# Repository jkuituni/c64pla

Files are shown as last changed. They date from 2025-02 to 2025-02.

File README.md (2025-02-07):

# c64pla
Implementation of the SuperPLA in the c64 'c' version in VHDL done together with Frank Buss. Note, that this version does work only as the normal SuperPLA (chip number 251715), not the one with integrated color SRAM (chip number 252535).

This is a fork from the Frank Buss' repository as that is where the original work was done. For additional information check out the webpage about this project :

https://frank-buss.de/c64/pla/index.html

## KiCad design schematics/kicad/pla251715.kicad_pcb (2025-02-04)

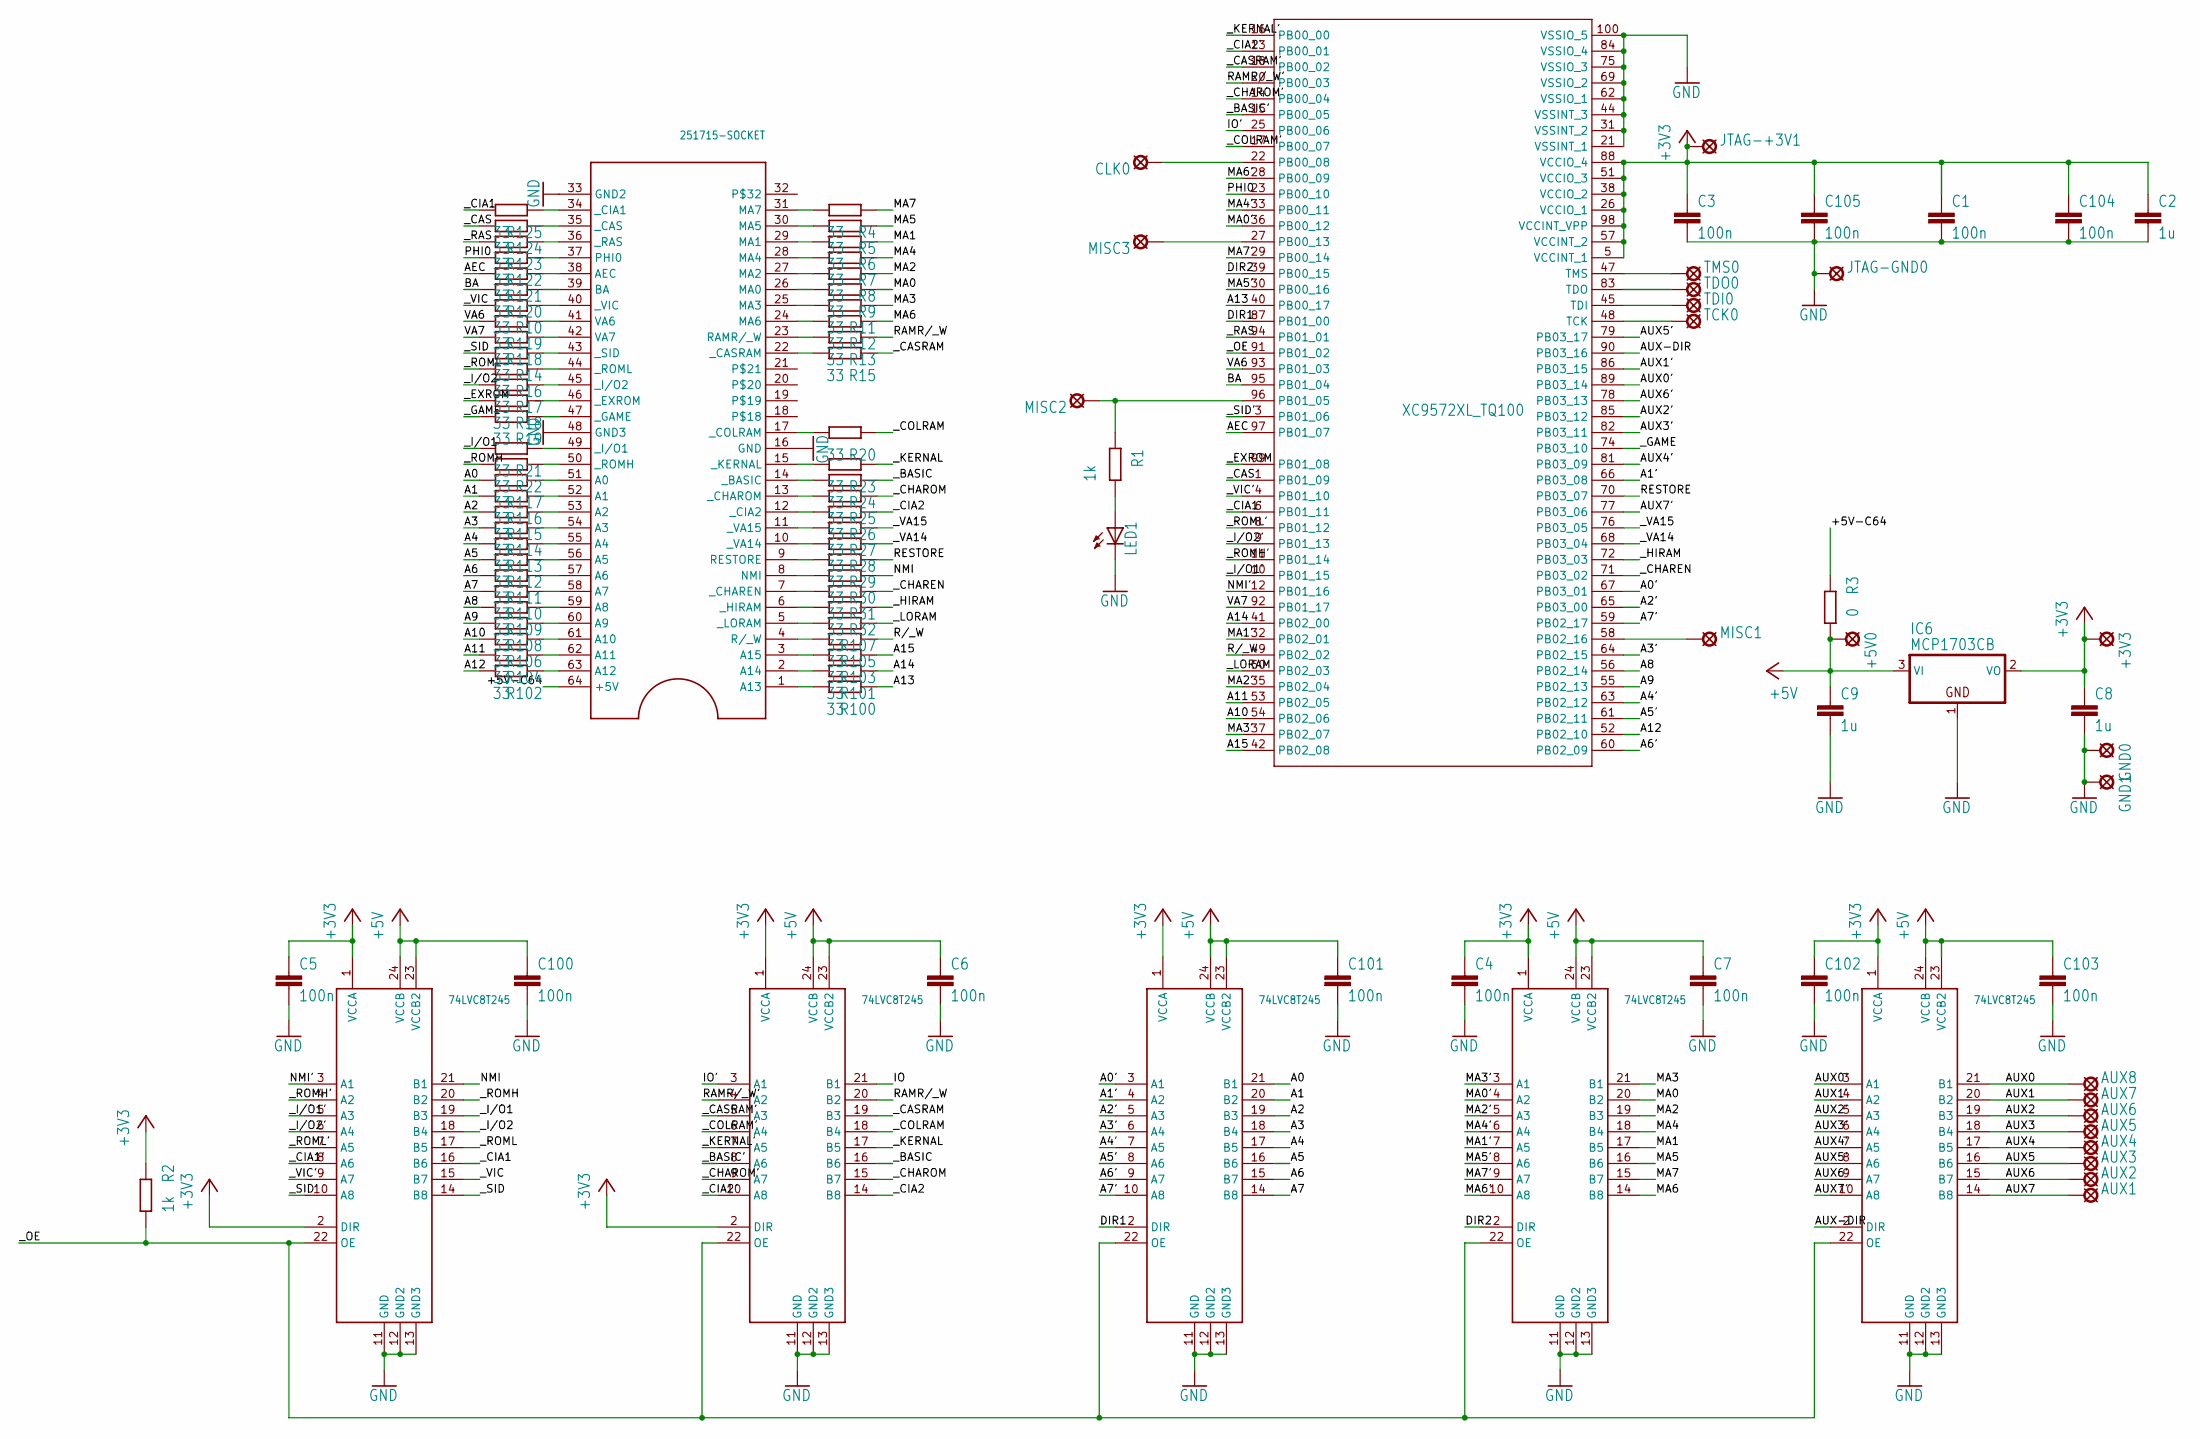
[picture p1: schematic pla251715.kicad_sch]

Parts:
+3V3, +5V0: LSP10
AUX1, AUX2, AUX3, AUX4, AUX5, AUX6, AUX7, AUX8: LSP10
C1, C3, C4, C5, C6, C7, C100, C101, C102, C103, C104, C105: 100n; C0603
C2, C8, C9: 1u; C1210
CLK0: LSP10
GND0, GND1: LSP10
IC1, IC3, IC4, IC5, IC100: 74LVC8T245; TSSOP24
IC2: XC9572XL_TQ100; TQ100
IC6: MCP1703CB; SOT23
JTAG-+3V1: LSP10
JTAG-GND0: LSP10
LED1: LED5MM
MISC1, MISC2, MISC3: LSP10
PLA-SOCKET0: 251715-SOCKET; 64-SPDIP
R1, R2: 1k; R0805
R3: 0; R0805
R4, R5, R6, R7, R8, R9, R10, R11, R12, R13, R14, R15, R16, R17, R18, R19, R20, R21, R22, R23, R24, R25, R26, R27, R28, R29, R30, R31, R32, R100, R101, R102, R103, R104, R105, R106, R107, R108, R109, R110, R111, R112, R113, R114, R115, R116, R117, R118, R119, R120, R121, R122, R123, R124, R125: 33; R0402
TCK0: LSP10
TDI0: LSP10
TDO0: LSP10
TMS0: LSP10

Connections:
+3V3: +3V3.MP, C1.1, C2.1, C3.1, C4.1, C5.1, C8.1, C102.1, C104.1, C105.1, IC1.1 (VCCA), IC2.5 (VCCINT_1), IC2.26 (VCCIO_1), IC2.38 (VCCIO_2), IC2.51 (VCCIO_3), IC2.57 (VCCINT_2), IC2.88 (VCCIO_4), IC2.98 (VCCINT_VPP), IC3.1 (VCCA), IC3.2 (DIR), IC4.1 (VCCA), IC4.2 (DIR), IC5.1 (VCCA), IC6.2 (VO), IC100.1 (VCCA), JTAG-+3V1.MP, R2.1
+5V: +5V0.MP, C6.1, C7.1, C9.1, C100.1, C101.1, C103.1, IC1.23 (VCCB2), IC1.24 (VCCB), IC3.23 (VCCB2), IC3.24 (VCCB), IC4.23 (VCCB2), IC4.24 (VCCB), IC5.23 (VCCB2), IC5.24 (VCCB), IC6.3 (VI), IC100.23 (VCCB2), IC100.24 (VCCB), R3.2
+5V-C64: PLA-SOCKET0.64 (+5V), R3.1
A0: IC100.21 (B1), R117.2
A0': IC2.67 (PB03_01), IC100.3 (A1)
A1: IC100.20 (B2), R116.2
A1': IC2.66 (PB03_08), IC100.4 (A2)
A2: IC100.19 (B3), R115.2
A2': IC2.65 (PB03_00), IC100.5 (A3)
A3: IC100.18 (B4), R114.2
A3': IC2.64 (PB02_15), IC100.6 (A4)
A4: IC100.17 (B5), R113.2
A4': IC2.63 (PB02_12), IC100.7 (A5)
A5: IC100.16 (B6), R112.2
A5': IC2.61 (PB02_11), IC100.8 (A6)
A6: IC100.15 (B7), R111.2
A6': IC2.60 (PB02_09), IC100.9 (A7)
A7: IC100.14 (B8), R110.2
A7': IC2.59 (PB02_17), IC100.10 (A8)
A8: IC2.56 (PB02_14), R109.2
A9: IC2.55 (PB02_13), R108.2
A10: IC2.54 (PB02_06), R106.2
A11: IC2.53 (PB02_05), R104.2
A12: IC2.52 (PB02_10), R102.2
A13: IC2.40 (PB00_17), R100.1
A14: IC2.41 (PB02_00), R101.1
A15: IC2.42 (PB02_08), R103.1
AEC: IC2.97 (PB01_07), R121.2
AUX0: AUX8.MP, IC1.21 (B1)
AUX0': IC1.3 (A1), IC2.89 (PB03_14)
AUX1: AUX7.MP, IC1.20 (B2)
AUX1': IC1.4 (A2), IC2.86 (PB03_15)
AUX2: AUX6.MP, IC1.19 (B3)
AUX2': IC1.5 (A3), IC2.85 (PB03_12)
AUX3: AUX5.MP, IC1.18 (B4)
AUX3': IC1.6 (A4), IC2.82 (PB03_11)
AUX4: AUX4.MP, IC1.17 (B5)
AUX4': IC1.7 (A5), IC2.81 (PB03_09)
AUX5: AUX3.MP, IC1.16 (B6)
AUX5': IC1.8 (A6), IC2.79 (PB03_17)
AUX6: AUX2.MP, IC1.15 (B7)
AUX6': IC1.9 (A7), IC2.78 (PB03_13)
AUX7: AUX1.MP, IC1.14 (B8)
AUX7': IC1.10 (A8), IC2.77 (PB03_06)
AUX-DIR: IC1.2 (DIR), IC2.90 (PB03_16)
BA: IC2.95 (PB01_04), R120.2
DIR1: IC2.87 (PB01_00), IC100.2 (DIR)
DIR2: IC2.39 (PB00_15), IC5.2 (DIR)
GND: C1.2, C2.2, C3.2, C4.2, C5.2, C6.2, C7.2, C8.2, C9.2, C100.2, C101.2, C102.2, C103.2, C104.2, C105.2, GND0.MP, GND1.MP, IC1.11 (GND), IC1.12 (GND2), IC1.13 (GND3), IC2.21 (VSSINT_1), IC2.31 (VSSINT_2), IC2.44 (VSSINT_3), IC2.62 (VSSIO_1), IC2.69 (VSSIO_2), IC2.75 (VSSIO_3), IC2.84 (VSSIO_4), IC2.100 (VSSIO_5), IC3.11 (GND), IC3.12 (GND2), IC3.13 (GND3), IC4.11 (GND), IC4.12 (GND2), IC4.13 (GND3), IC5.11 (GND), IC5.12 (GND2), IC5.13 (GND3), IC6.1 (GND), IC100.11 (GND), IC100.12 (GND2), IC100.13 (GND3), JTAG-GND0.MP, LED1.K (C), PLA-SOCKET0.16 (GND), PLA-SOCKET0.33 (GND2), PLA-SOCKET0.48 (GND3)
IO: IC4.21 (B1)
IO': IC2.25 (PB00_06), IC4.3 (A1)
MA0: IC5.20 (B2), R9.1
MA0': IC2.36 (PB00_12), IC5.4 (A2)
MA1: IC5.17 (B5), R6.1
MA1': IC2.32 (PB02_01), IC5.7 (A5)
MA2: IC5.19 (B3), R8.1
MA2': IC2.35 (PB02_04), IC5.5 (A3)
MA3: IC5.21 (B1), R11.1
MA3': IC2.37 (PB02_07), IC5.3 (A1)
MA4: IC5.18 (B4), R7.1
MA4': IC2.33 (PB00_11), IC5.6 (A4)
MA5: IC5.16 (B6), R5.1
MA5': IC2.30 (PB00_16), IC5.8 (A6)
MA6: IC5.14 (B8), R12.1
MA6': IC2.28 (PB00_09), IC5.10 (A8)
MA7: IC5.15 (B7), R4.1
MA7': IC2.29 (PB00_14), IC5.9 (A7)
unnamed: IC2.96 (PB01_05), MISC2.MP, R1.1
unnamed: IC2.58 (PB02_16), MISC1.MP
unnamed: IC2.27 (PB00_13), MISC3.MP
unnamed: LED1.A, R1.2
unnamed: CLK0.MP, IC2.22 (PB00_08)
unnamed: PLA-SOCKET0.17 (_COLRAM), R20.2
unnamed: PLA-SOCKET0.31 (MA7), R4.2
unnamed: PLA-SOCKET0.30 (MA5), R5.2
unnamed: PLA-SOCKET0.15 (_KERNAL), R23.2
unnamed: PLA-SOCKET0.29 (MA1), R6.2
unnamed: PLA-SOCKET0.28 (MA4), R7.2
unnamed: PLA-SOCKET0.27 (MA2), R8.2
unnamed: PLA-SOCKET0.26 (MA0), R9.2
unnamed: PLA-SOCKET0.25 (MA3), R11.2
unnamed: PLA-SOCKET0.24 (MA6), R12.2
unnamed: PLA-SOCKET0.23 (RAMR/_W), R13.2
unnamed: PLA-SOCKET0.22 (_CASRAM), R15.2
unnamed: PLA-SOCKET0.14 (_BASIC), R24.2
unnamed: PLA-SOCKET0.13 (_CHAROM), R25.2
unnamed: PLA-SOCKET0.12 (_CIA2), R26.2
unnamed: PLA-SOCKET0.11 (_VA15), R27.2
unnamed: PLA-SOCKET0.10 (_VA14), R28.2
unnamed: PLA-SOCKET0.9 (RESTORE), R29.2
unnamed: PLA-SOCKET0.8 (NMI), R30.2
unnamed: PLA-SOCKET0.7 (_CHAREN), R31.2
unnamed: PLA-SOCKET0.6 (_HIRAM), R32.2
unnamed: PLA-SOCKET0.5 (_LORAM), R107.2
unnamed: PLA-SOCKET0.4 (R/_W), R105.2
unnamed: PLA-SOCKET0.3 (A15), R103.2
unnamed: PLA-SOCKET0.2 (A14), R101.2
unnamed: PLA-SOCKET0.1 (A13), R100.2
unnamed: PLA-SOCKET0.63 (A12), R102.1
unnamed: PLA-SOCKET0.62 (A11), R104.1
unnamed: PLA-SOCKET0.61 (A10), R106.1
unnamed: PLA-SOCKET0.60 (A9), R108.1
unnamed: PLA-SOCKET0.59 (A8), R109.1
unnamed: PLA-SOCKET0.58 (A7), R110.1
unnamed: PLA-SOCKET0.57 (A6), R111.1
unnamed: PLA-SOCKET0.56 (A5), R112.1
unnamed: PLA-SOCKET0.55 (A4), R113.1
unnamed: PLA-SOCKET0.54 (A3), R114.1
unnamed: PLA-SOCKET0.53 (A2), R115.1
unnamed: PLA-SOCKET0.52 (A1), R116.1
unnamed: PLA-SOCKET0.51 (A0), R117.1
unnamed: PLA-SOCKET0.50 (_ROMH), R22.1
unnamed: PLA-SOCKET0.49 (_I/O1), R21.1
unnamed: PLA-SOCKET0.47 (_GAME), R19.1
unnamed: PLA-SOCKET0.46 (_EXROM), R18.1
unnamed: PLA-SOCKET0.45 (_I/O2), R17.1
unnamed: PLA-SOCKET0.44 (_ROML), R16.1
unnamed: PLA-SOCKET0.43 (_SID), R14.1
unnamed: PLA-SOCKET0.42 (VA7), R118.1
unnamed: PLA-SOCKET0.41 (VA6), R119.1
unnamed: PLA-SOCKET0.40 (_VIC), R10.1
unnamed: PLA-SOCKET0.39 (BA), R120.1
unnamed: PLA-SOCKET0.38 (AEC), R121.1
unnamed: PLA-SOCKET0.37 (PHI0), R122.1
unnamed: PLA-SOCKET0.36 (_RAS), R123.1
unnamed: PLA-SOCKET0.35 (_CAS), R124.1
unnamed: PLA-SOCKET0.34 (_CIA1), R125.1
NMI: IC3.21 (B1), R30.1
NMI': IC2.12 (PB01_16), IC3.3 (A1)
PHI0: IC2.23 (PB00_10), R122.2
R/_W: IC2.49 (PB02_02), R105.1
RAMR/_W: IC4.20 (B2), R13.1
RAMR/_W': IC2.20 (PB00_03), IC4.4 (A2)
RESTORE: IC2.70 (PB03_07), R29.1
TCK: IC2.48 (TCK), TCK0.MP
TDI: IC2.45 (TDI), TDI0.MP
TDO: IC2.83 (TDO), TDO0.MP
TMS: IC2.47 (TMS), TMS0.MP
VA6: IC2.93 (PB01_03), R119.2
VA7: IC2.92 (PB01_17), R118.2
_BASIC: IC4.16 (B6), R24.1
_BASIC': IC2.15 (PB00_05), IC4.8 (A6)
_CAS: IC2.1 (PB01_09), R124.2
_CASRAM: IC4.19 (B3), R15.1
_CASRAM': IC2.18 (PB00_02), IC4.5 (A3)
_CHAREN: IC2.71 (PB03_02), R31.1
_CHAROM: IC4.15 (B7), R25.1
_CHAROM': IC2.14 (PB00_04), IC4.9 (A7)
_CIA1: IC3.16 (B6), R125.2
_CIA1': IC2.6 (PB01_11), IC3.8 (A6)
_CIA2: IC4.14 (B8), R26.1
_CIA2': IC2.13 (PB00_01), IC4.10 (A8)
_COLRAM: IC4.18 (B4), R20.1
_COLRAM': IC2.17 (PB00_07), IC4.6 (A4)
_EXROM: IC2.99 (PB01_08), R18.2
_GAME: IC2.74 (PB03_10), R19.2
_HIRAM: IC2.72 (PB03_03), R32.1
_I/O1: IC3.19 (B3), R21.2
_I/O1': IC2.10 (PB01_15), IC3.5 (A3)
_I/O2: IC3.18 (B4), R17.2
_I/O2': IC2.9 (PB01_13), IC3.6 (A4)
_KERNAL: IC4.17 (B5), R23.1
_KERNAL': IC2.16 (PB00_00), IC4.7 (A5)
_LORAM: IC2.50 (PB02_03), R107.1
_OE: IC1.22 (OE), IC2.91 (PB01_02), IC3.22 (OE), IC4.22 (OE), IC5.22 (OE), IC100.22 (OE), R2.2
_RAS: IC2.94 (PB01_01), R123.2
_ROMH: IC3.20 (B2), R22.2
_ROMH': IC2.11 (PB01_14), IC3.4 (A2)
_ROML: IC3.17 (B5), R16.2
_ROML': IC2.8 (PB01_12), IC3.7 (A5)
_SID: IC3.14 (B8), R14.2
_SID': IC2.3 (PB01_06), IC3.10 (A8)
_VA14: IC2.68 (PB03_04), R28.1
_VA15: IC2.76 (PB03_05), R27.1
_VIC: IC3.15 (B7), R10.2
_VIC': IC2.4 (PB01_10), IC3.9 (A7)

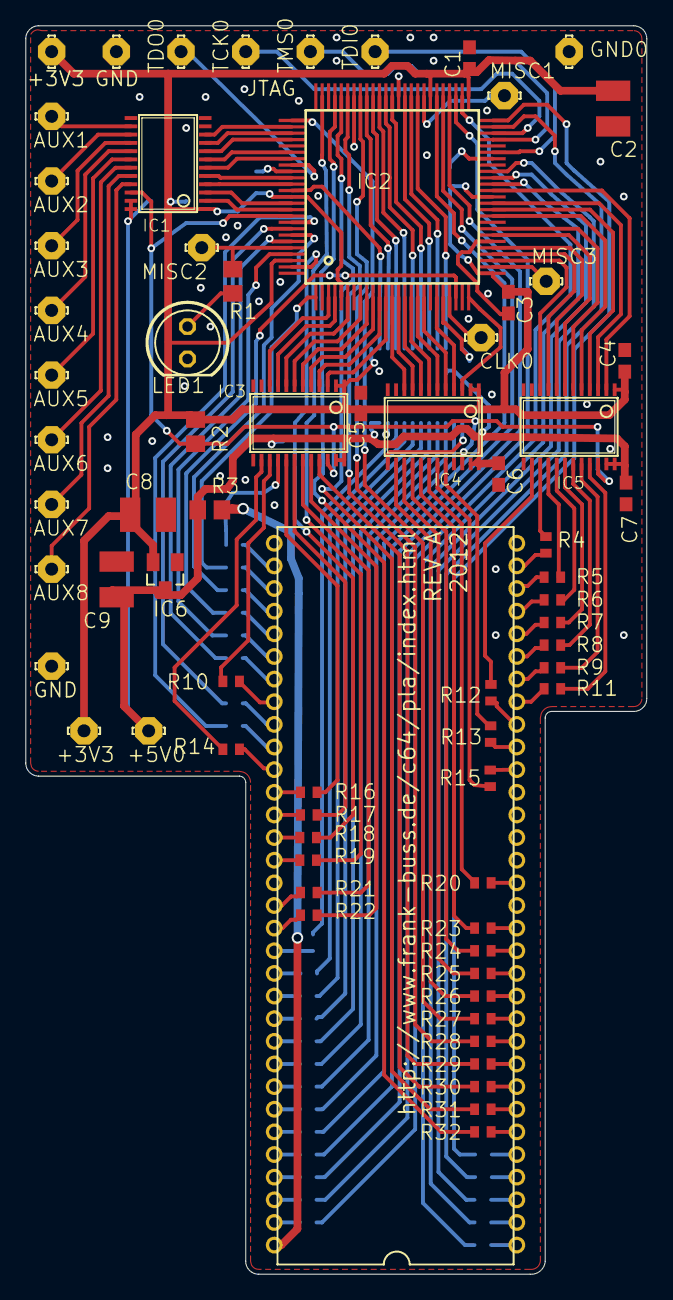
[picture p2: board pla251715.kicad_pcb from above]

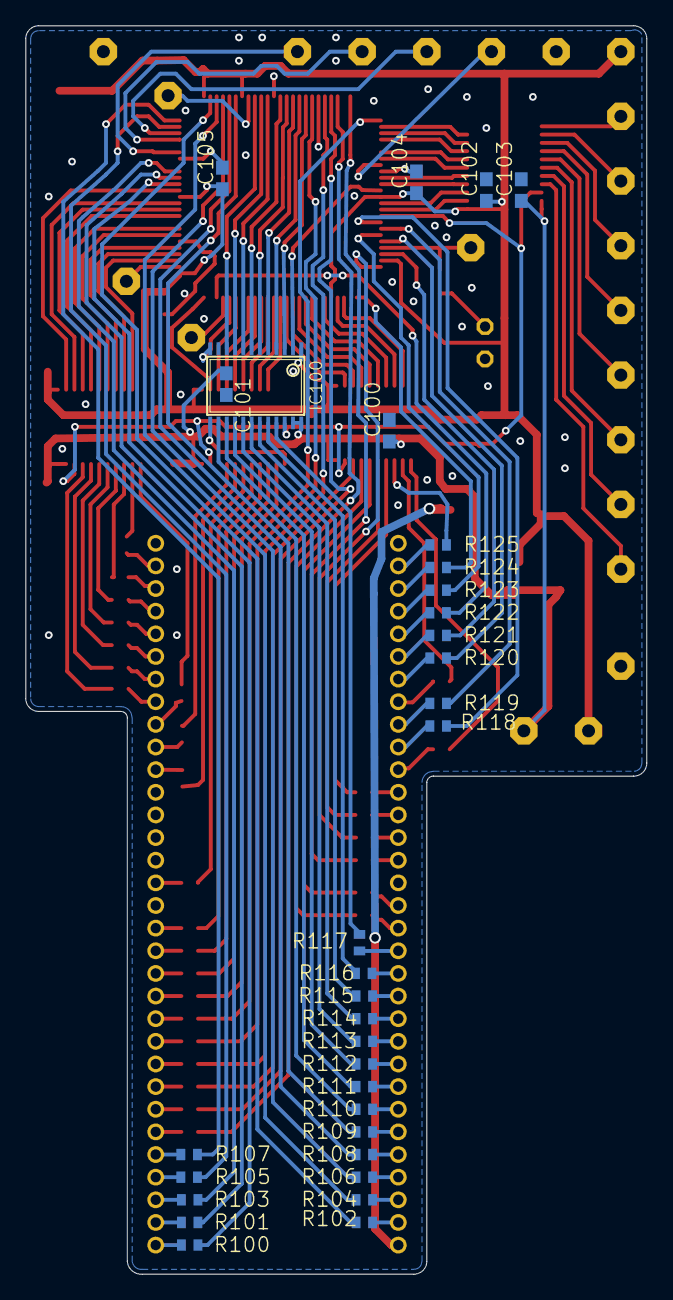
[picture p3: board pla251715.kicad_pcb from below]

Board: 2 copper layers, 48.8 x 98.0 mm, 104 parts (33 on the bottom side), 175 nets.

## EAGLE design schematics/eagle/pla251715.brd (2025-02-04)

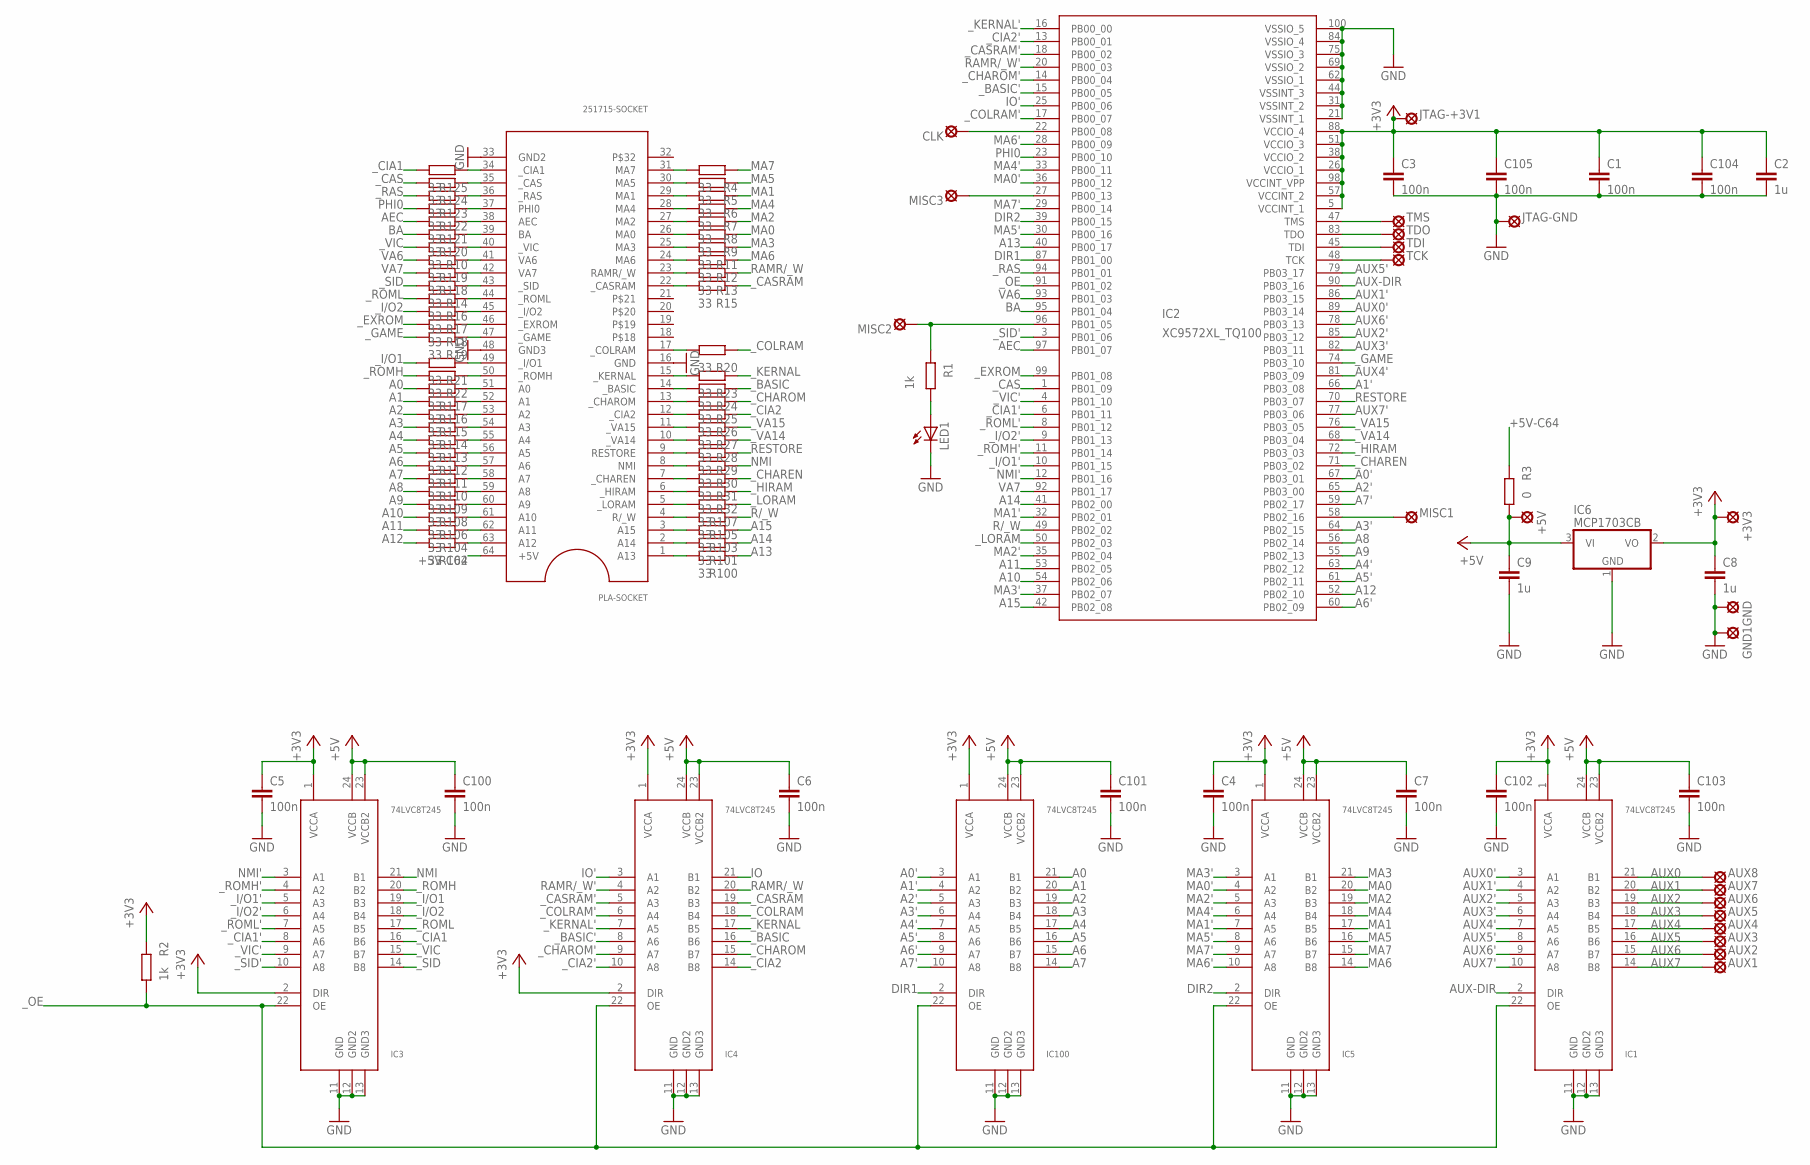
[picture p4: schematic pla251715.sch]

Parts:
+3V3, +5V: LSP10
AUX1, AUX2, AUX3, AUX4, AUX5, AUX6, AUX7, AUX8: LSP10
C1, C3, C4, C5, C6, C7, C100, C101, C102, C103, C104, C105: 100n; C0603
C2, C8, C9: 1u; C1210
CLK: LSP10
GND, GND1: LSP10
IC1, IC3, IC4, IC5, IC100: 74LVC8T245; TSSOP24
IC2: XC9572XL_TQ100; TQ100
IC6: MCP1703CB; SOT23
JTAG-+3V1: LSP10
JTAG-GND: LSP10
LED1: LED5MM
MISC1, MISC2, MISC3: LSP10
PLA-SOCKET: 251715-SOCKET; 64-SPDIP
R1, R2: 1k; R0805
R3: 0; R0805
R4, R5, R6, R7, R8, R9, R10, R11, R12, R13, R14, R15, R16, R17, R18, R19, R20, R21, R22, R23, R24, R25, R26, R27, R28, R29, R30, R31, R32, R100, R101, R102, R103, R104, R105, R106, R107, R108, R109, R110, R111, R112, R113, R114, R115, R116, R117, R118, R119, R120, R121, R122, R123, R124, R125: 33; R0402
TCK: LSP10
TDI: LSP10
TDO: LSP10
TMS: LSP10

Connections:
+3V3: +3V3.MP, C1.1, C2.1, C3.1, C4.1, C5.1, C8.1, C102.1, C104.1, C105.1, IC1.1 (VCCA), IC2.5 (VCCINT_1), IC2.26 (VCCIO_1), IC2.38 (VCCIO_2), IC2.51 (VCCIO_3), IC2.57 (VCCINT_2), IC2.88 (VCCIO_4), IC2.98 (VCCINT_VPP), IC3.1 (VCCA), IC3.2 (DIR), IC4.1 (VCCA), IC4.2 (DIR), IC5.1 (VCCA), IC6.2 (VO), IC100.1 (VCCA), JTAG-+3V1.MP, R2.1
+5V: +5V.MP, C6.1, C7.1, C9.1, C100.1, C101.1, C103.1, IC1.23 (VCCB2), IC1.24 (VCCB), IC3.23 (VCCB2), IC3.24 (VCCB), IC4.23 (VCCB2), IC4.24 (VCCB), IC5.23 (VCCB2), IC5.24 (VCCB), IC6.3 (VI), IC100.23 (VCCB2), IC100.24 (VCCB), R3.2
+5V-C64: PLA-SOCKET.64 (+5V), R3.1
A0: IC100.21 (B1), R117.2
A0': IC2.67 (PB03_01), IC100.3 (A1)
A1: IC100.20 (B2), R116.2
A1': IC2.66 (PB03_08), IC100.4 (A2)
A2: IC100.19 (B3), R115.2
A2': IC2.65 (PB03_00), IC100.5 (A3)
A3: IC100.18 (B4), R114.2
A3': IC2.64 (PB02_15), IC100.6 (A4)
A4: IC100.17 (B5), R113.2
A4': IC2.63 (PB02_12), IC100.7 (A5)
A5: IC100.16 (B6), R112.2
A5': IC2.61 (PB02_11), IC100.8 (A6)
A6: IC100.15 (B7), R111.2
A6': IC2.60 (PB02_09), IC100.9 (A7)
A7: IC100.14 (B8), R110.2
A7': IC2.59 (PB02_17), IC100.10 (A8)
A8: IC2.56 (PB02_14), R109.2
A9: IC2.55 (PB02_13), R108.2
A10: IC2.54 (PB02_06), R106.2
A11: IC2.53 (PB02_05), R104.2
A12: IC2.52 (PB02_10), R102.2
A13: IC2.40 (PB00_17), R100.1
A14: IC2.41 (PB02_00), R101.1
A15: IC2.42 (PB02_08), R103.1
AEC: IC2.97 (PB01_07), R121.2
AUX0: AUX8.MP, IC1.21 (B1)
AUX0': IC1.3 (A1), IC2.89 (PB03_14)
AUX1: AUX7.MP, IC1.20 (B2)
AUX1': IC1.4 (A2), IC2.86 (PB03_15)
AUX2: AUX6.MP, IC1.19 (B3)
AUX2': IC1.5 (A3), IC2.85 (PB03_12)
AUX3: AUX5.MP, IC1.18 (B4)
AUX3': IC1.6 (A4), IC2.82 (PB03_11)
AUX4: AUX4.MP, IC1.17 (B5)
AUX4': IC1.7 (A5), IC2.81 (PB03_09)
AUX5: AUX3.MP, IC1.16 (B6)
AUX5': IC1.8 (A6), IC2.79 (PB03_17)
AUX6: AUX2.MP, IC1.15 (B7)
AUX6': IC1.9 (A7), IC2.78 (PB03_13)
AUX7: AUX1.MP, IC1.14 (B8)
AUX7': IC1.10 (A8), IC2.77 (PB03_06)
AUX-DIR: IC1.2 (DIR), IC2.90 (PB03_16)
BA: IC2.95 (PB01_04), R120.2
DIR1: IC2.87 (PB01_00), IC100.2 (DIR)
DIR2: IC2.39 (PB00_15), IC5.2 (DIR)
GND: C1.2, C2.2, C3.2, C4.2, C5.2, C6.2, C7.2, C8.2, C9.2, C100.2, C101.2, C102.2, C103.2, C104.2, C105.2, GND.MP, GND1.MP, IC1.11 (GND), IC1.12 (GND2), IC1.13 (GND3), IC2.21 (VSSINT_1), IC2.31 (VSSINT_2), IC2.44 (VSSINT_3), IC2.62 (VSSIO_1), IC2.69 (VSSIO_2), IC2.75 (VSSIO_3), IC2.84 (VSSIO_4), IC2.100 (VSSIO_5), IC3.11 (GND), IC3.12 (GND2), IC3.13 (GND3), IC4.11 (GND), IC4.12 (GND2), IC4.13 (GND3), IC5.11 (GND), IC5.12 (GND2), IC5.13 (GND3), IC6.1 (GND), IC100.11 (GND), IC100.12 (GND2), IC100.13 (GND3), JTAG-GND.MP, LED1.K (C), PLA-SOCKET.16 (GND), PLA-SOCKET.33 (GND2), PLA-SOCKET.48 (GND3)
IO: IC4.21 (B1)
IO': IC2.25 (PB00_06), IC4.3 (A1)
MA0: IC5.20 (B2), R9.1
MA0': IC2.36 (PB00_12), IC5.4 (A2)
MA1: IC5.17 (B5), R6.1
MA1': IC2.32 (PB02_01), IC5.7 (A5)
MA2: IC5.19 (B3), R8.1
MA2': IC2.35 (PB02_04), IC5.5 (A3)
MA3: IC5.21 (B1), R11.1
MA3': IC2.37 (PB02_07), IC5.3 (A1)
MA4: IC5.18 (B4), R7.1
MA4': IC2.33 (PB00_11), IC5.6 (A4)
MA5: IC5.16 (B6), R5.1
MA5': IC2.30 (PB00_16), IC5.8 (A6)
MA6: IC5.14 (B8), R12.1
MA6': IC2.28 (PB00_09), IC5.10 (A8)
MA7: IC5.15 (B7), R4.1
MA7': IC2.29 (PB00_14), IC5.9 (A7)
unnamed: IC2.96 (PB01_05), MISC2.MP, R1.1
unnamed: IC2.58 (PB02_16), MISC1.MP
unnamed: IC2.27 (PB00_13), MISC3.MP
unnamed: LED1.A, R1.2
unnamed: CLK.MP, IC2.22 (PB00_08)
unnamed: PLA-SOCKET.17 (_COLRAM), R20.2
unnamed: PLA-SOCKET.31 (MA7), R4.2
unnamed: PLA-SOCKET.30 (MA5), R5.2
unnamed: PLA-SOCKET.15 (_KERNAL), R23.2
unnamed: PLA-SOCKET.29 (MA1), R6.2
unnamed: PLA-SOCKET.28 (MA4), R7.2
unnamed: PLA-SOCKET.27 (MA2), R8.2
unnamed: PLA-SOCKET.26 (MA0), R9.2
unnamed: PLA-SOCKET.25 (MA3), R11.2
unnamed: PLA-SOCKET.24 (MA6), R12.2
unnamed: PLA-SOCKET.23 (RAMR/_W), R13.2
unnamed: PLA-SOCKET.22 (_CASRAM), R15.2
unnamed: PLA-SOCKET.14 (_BASIC), R24.2
unnamed: PLA-SOCKET.13 (_CHAROM), R25.2
unnamed: PLA-SOCKET.12 (_CIA2), R26.2
unnamed: PLA-SOCKET.11 (_VA15), R27.2
unnamed: PLA-SOCKET.10 (_VA14), R28.2
unnamed: PLA-SOCKET.9 (RESTORE), R29.2
unnamed: PLA-SOCKET.8 (NMI), R30.2
unnamed: PLA-SOCKET.7 (_CHAREN), R31.2
unnamed: PLA-SOCKET.6 (_HIRAM), R32.2
unnamed: PLA-SOCKET.5 (_LORAM), R107.2
unnamed: PLA-SOCKET.4 (R/_W), R105.2
unnamed: PLA-SOCKET.3 (A15), R103.2
unnamed: PLA-SOCKET.2 (A14), R101.2
unnamed: PLA-SOCKET.1 (A13), R100.2
unnamed: PLA-SOCKET.63 (A12), R102.1
unnamed: PLA-SOCKET.62 (A11), R104.1
unnamed: PLA-SOCKET.61 (A10), R106.1
unnamed: PLA-SOCKET.60 (A9), R108.1
unnamed: PLA-SOCKET.59 (A8), R109.1
unnamed: PLA-SOCKET.58 (A7), R110.1
unnamed: PLA-SOCKET.57 (A6), R111.1
unnamed: PLA-SOCKET.56 (A5), R112.1
unnamed: PLA-SOCKET.55 (A4), R113.1
unnamed: PLA-SOCKET.54 (A3), R114.1
unnamed: PLA-SOCKET.53 (A2), R115.1
unnamed: PLA-SOCKET.52 (A1), R116.1
unnamed: PLA-SOCKET.51 (A0), R117.1
unnamed: PLA-SOCKET.50 (_ROMH), R22.1
unnamed: PLA-SOCKET.49 (_I/O1), R21.1
unnamed: PLA-SOCKET.47 (_GAME), R19.1
unnamed: PLA-SOCKET.46 (_EXROM), R18.1
unnamed: PLA-SOCKET.45 (_I/O2), R17.1
unnamed: PLA-SOCKET.44 (_ROML), R16.1
unnamed: PLA-SOCKET.43 (_SID), R14.1
unnamed: PLA-SOCKET.42 (VA7), R118.1
unnamed: PLA-SOCKET.41 (VA6), R119.1
unnamed: PLA-SOCKET.40 (_VIC), R10.1
unnamed: PLA-SOCKET.39 (BA), R120.1
unnamed: PLA-SOCKET.38 (AEC), R121.1
unnamed: PLA-SOCKET.37 (PHI0), R122.1
unnamed: PLA-SOCKET.36 (_RAS), R123.1
unnamed: PLA-SOCKET.35 (_CAS), R124.1
unnamed: PLA-SOCKET.34 (_CIA1), R125.1
NMI: IC3.21 (B1), R30.1
NMI': IC2.12 (PB01_16), IC3.3 (A1)
PHI0: IC2.23 (PB00_10), R122.2
R/_W: IC2.49 (PB02_02), R105.1
RAMR/_W: IC4.20 (B2), R13.1
RAMR/_W': IC2.20 (PB00_03), IC4.4 (A2)
RESTORE: IC2.70 (PB03_07), R29.1
TCK: IC2.48 (TCK), TCK.MP
TDI: IC2.45 (TDI), TDI.MP
TDO: IC2.83 (TDO), TDO.MP
TMS: IC2.47 (TMS), TMS.MP
VA6: IC2.93 (PB01_03), R119.2
VA7: IC2.92 (PB01_17), R118.2
_BASIC: IC4.16 (B6), R24.1
_BASIC': IC2.15 (PB00_05), IC4.8 (A6)
_CAS: IC2.1 (PB01_09), R124.2
_CASRAM: IC4.19 (B3), R15.1
_CASRAM': IC2.18 (PB00_02), IC4.5 (A3)
_CHAREN: IC2.71 (PB03_02), R31.1
_CHAROM: IC4.15 (B7), R25.1
_CHAROM': IC2.14 (PB00_04), IC4.9 (A7)
_CIA1: IC3.16 (B6), R125.2
_CIA1': IC2.6 (PB01_11), IC3.8 (A6)
_CIA2: IC4.14 (B8), R26.1
_CIA2': IC2.13 (PB00_01), IC4.10 (A8)
_COLRAM: IC4.18 (B4), R20.1
_COLRAM': IC2.17 (PB00_07), IC4.6 (A4)
_EXROM: IC2.99 (PB01_08), R18.2
_GAME: IC2.74 (PB03_10), R19.2
_HIRAM: IC2.72 (PB03_03), R32.1
_I/O1: IC3.19 (B3), R21.2
_I/O1': IC2.10 (PB01_15), IC3.5 (A3)
_I/O2: IC3.18 (B4), R17.2
_I/O2': IC2.9 (PB01_13), IC3.6 (A4)
_KERNAL: IC4.17 (B5), R23.1
_KERNAL': IC2.16 (PB00_00), IC4.7 (A5)
_LORAM: IC2.50 (PB02_03), R107.1
_OE: IC1.22 (OE), IC2.91 (PB01_02), IC3.22 (OE), IC4.22 (OE), IC5.22 (OE), IC100.22 (OE), R2.2
_RAS: IC2.94 (PB01_01), R123.2
_ROMH: IC3.20 (B2), R22.2
_ROMH': IC2.11 (PB01_14), IC3.4 (A2)
_ROML: IC3.17 (B5), R16.2
_ROML': IC2.8 (PB01_12), IC3.7 (A5)
_SID: IC3.14 (B8), R14.2
_SID': IC2.3 (PB01_06), IC3.10 (A8)
_VA14: IC2.68 (PB03_04), R28.1
_VA15: IC2.76 (PB03_05), R27.1
_VIC: IC3.15 (B7), R10.2
_VIC': IC2.4 (PB01_10), IC3.9 (A7)

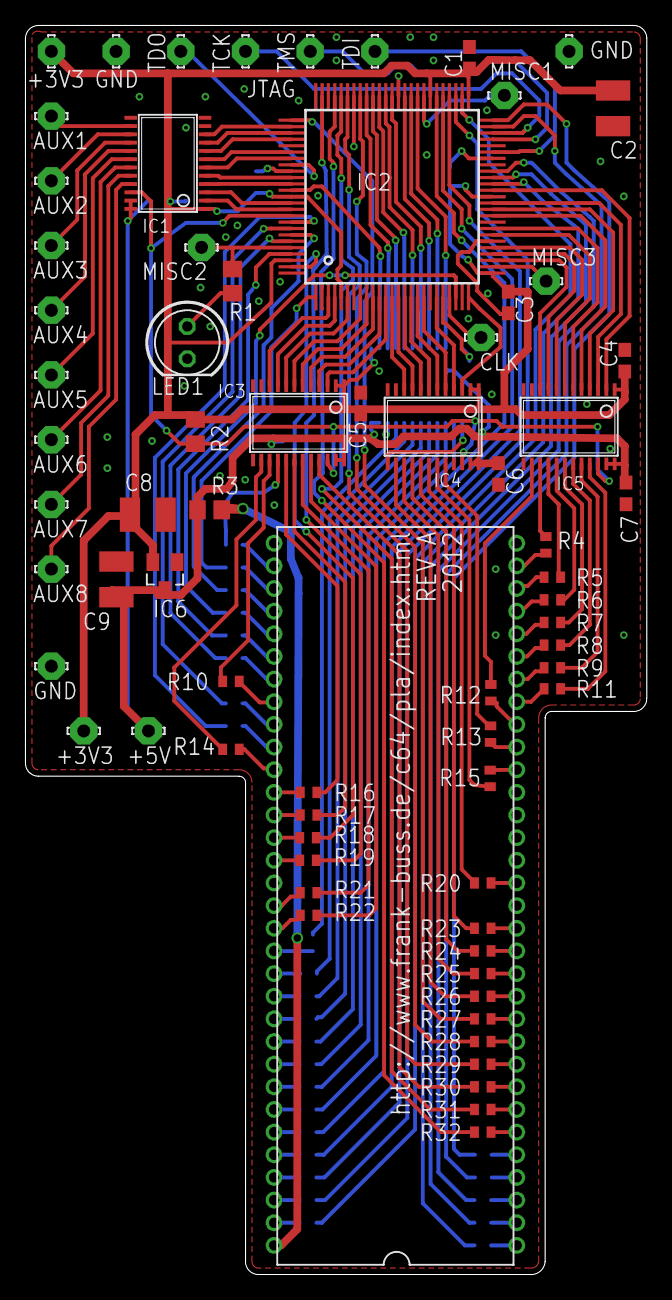
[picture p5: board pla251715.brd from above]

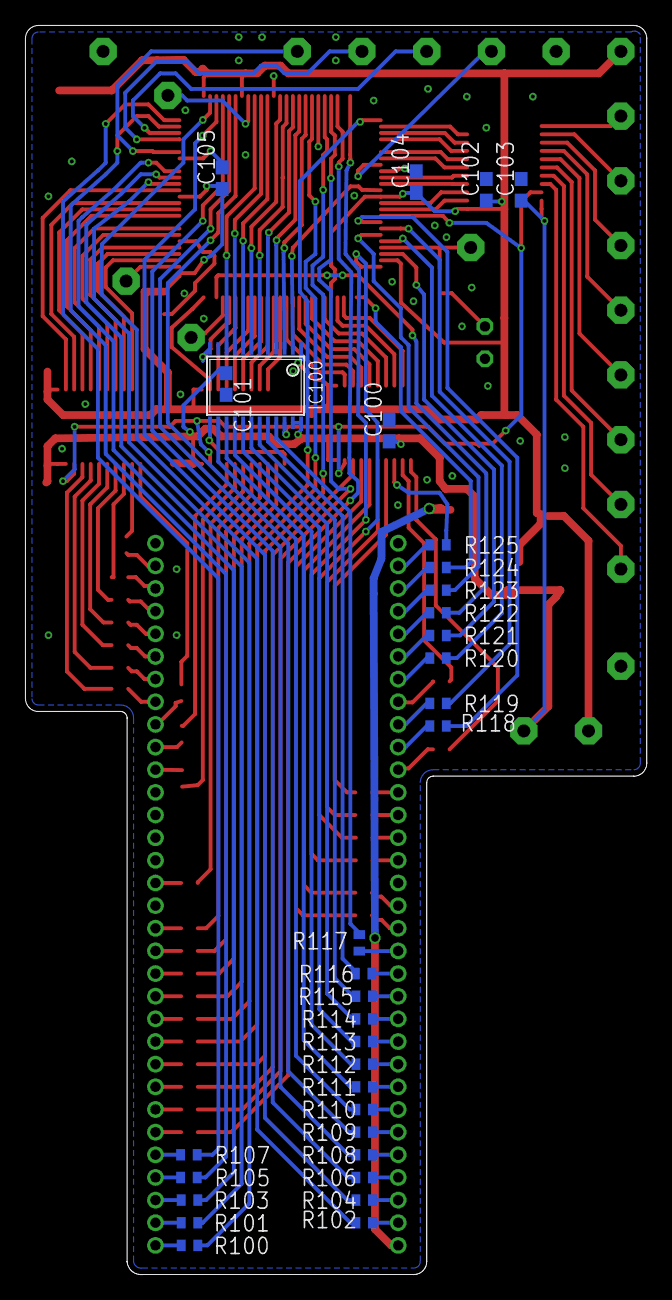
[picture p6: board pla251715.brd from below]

Board: 2 copper layers, 48.8 x 98.0 mm, 104 parts (33 on the bottom side), 175 nets.
